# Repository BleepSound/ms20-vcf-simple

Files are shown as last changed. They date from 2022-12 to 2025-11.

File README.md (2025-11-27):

[][cc-by-sa]

# MS20 VCF

Latest documentation available at https://bleepsound.github.io/modules/

[][cc-by-sa]

[cc-by-sa]: http://creativecommons.org/licenses/by-sa/4.0/
[cc-by-sa-image]: https://licensebuttons.net/l/by-sa/4.0/88x31.png
[cc-by-sa-shield]: https://img.shields.io/badge/License-CC%20BY--SA%204.0-lightgrey.svg

[][cc-by-sa]

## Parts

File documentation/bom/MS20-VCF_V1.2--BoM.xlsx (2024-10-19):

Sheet: BoM
MS20-VCF_V1.2 Bill of Materials
Schematic: | MS20-VCF | Component Groups: | 22
Variant: | default | Component Count: | 55 (0 SMD/ 53 THT)
Revision: | 1.2 | Fitted Components: | 55 (0 SMD/ 53 THT)
Date: | 2024-10-19 | Number of PCBs: | 1
KiCad Version: | 8.0.6-8.0.6-0~ubuntu22.04.1 | Total Components: | 55
Row | Description | References | Value | Quantity Per PCB | Comments
1 |  | C1 C4 C5 | 1nF | 3
2 |  | C7 C8 C9 C10 | 100nF | 4
3 |  | C2 C3 C6 | 10uF | 3
4 |  | CUTCV1 CUTOFF1 Res1 | 100k | 3
5 |  | D2 D3 D4 D5 D6 D7 | 1N4148 | 6
6 |  | D1 | LED-12V | 1
7 |  | FB1 FB2 | 10R | 2
8 |  | J6 J7 J8 | FilterCV1 | 3
9 |  | J5 | Power Input | 1
10 |  | Q1 Q2 | BC559 (https://www.onsemi.com/pub/Collateral/BC556BTA-D.pdf) | 2
11 |  | R1 R3 R12 R13 | 470 | 4
12 |  | R8 R21 R22 | 1k | 3
13 |  | R10 R19 | 1.8k | 2
14 |  | R4 R5 R9 R20 | 2.2k | 4
15 |  | R17 | 33k | 1
16 |  | R18 | 56k | 1
17 |  | R14 | 82k | 1
18 |  | R2 R6 R7 R11 R15 R16 | 100k | 6
19 |  | ResLv1 ResVol1 | 10k | 2
20 |  | SW1 | Hpass/Lpass Switch | 1
21 |  | U1 | LM13700 (http://www.ti.com/lit/ds/symlink/lm13700.pdf) | 1
22 |  | U2 | TL072 (http://www.ti.com/lit/ds/symlink/tl071.pdf) | 1

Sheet: Colors
Columns colors
KiCad Fields (default)
Generated Fields
User Fields
Empty Fields

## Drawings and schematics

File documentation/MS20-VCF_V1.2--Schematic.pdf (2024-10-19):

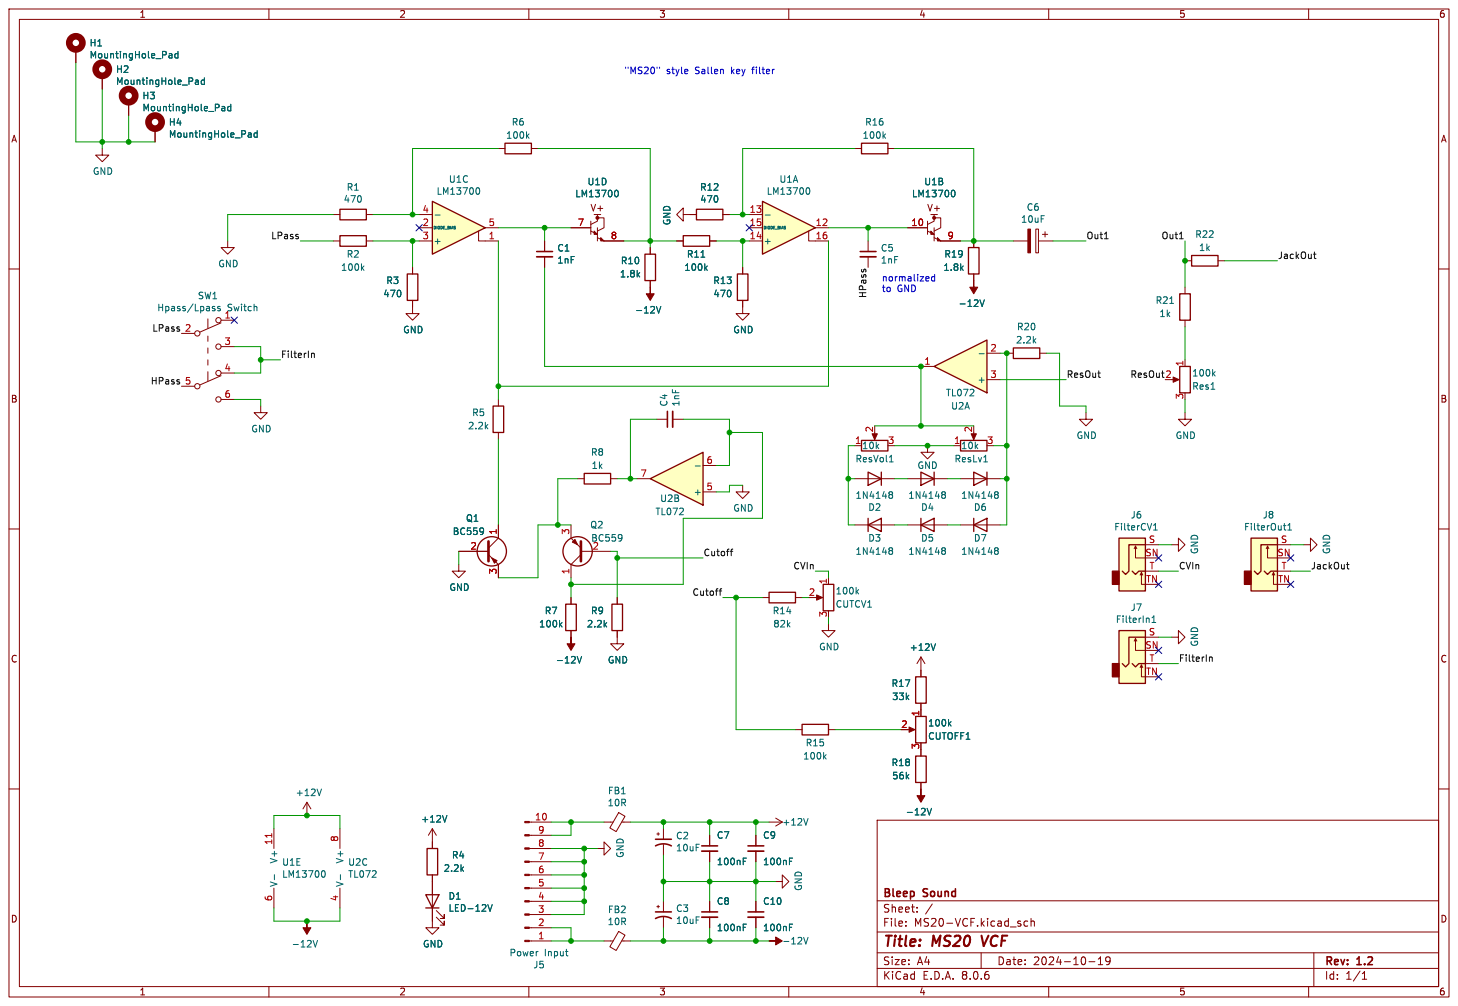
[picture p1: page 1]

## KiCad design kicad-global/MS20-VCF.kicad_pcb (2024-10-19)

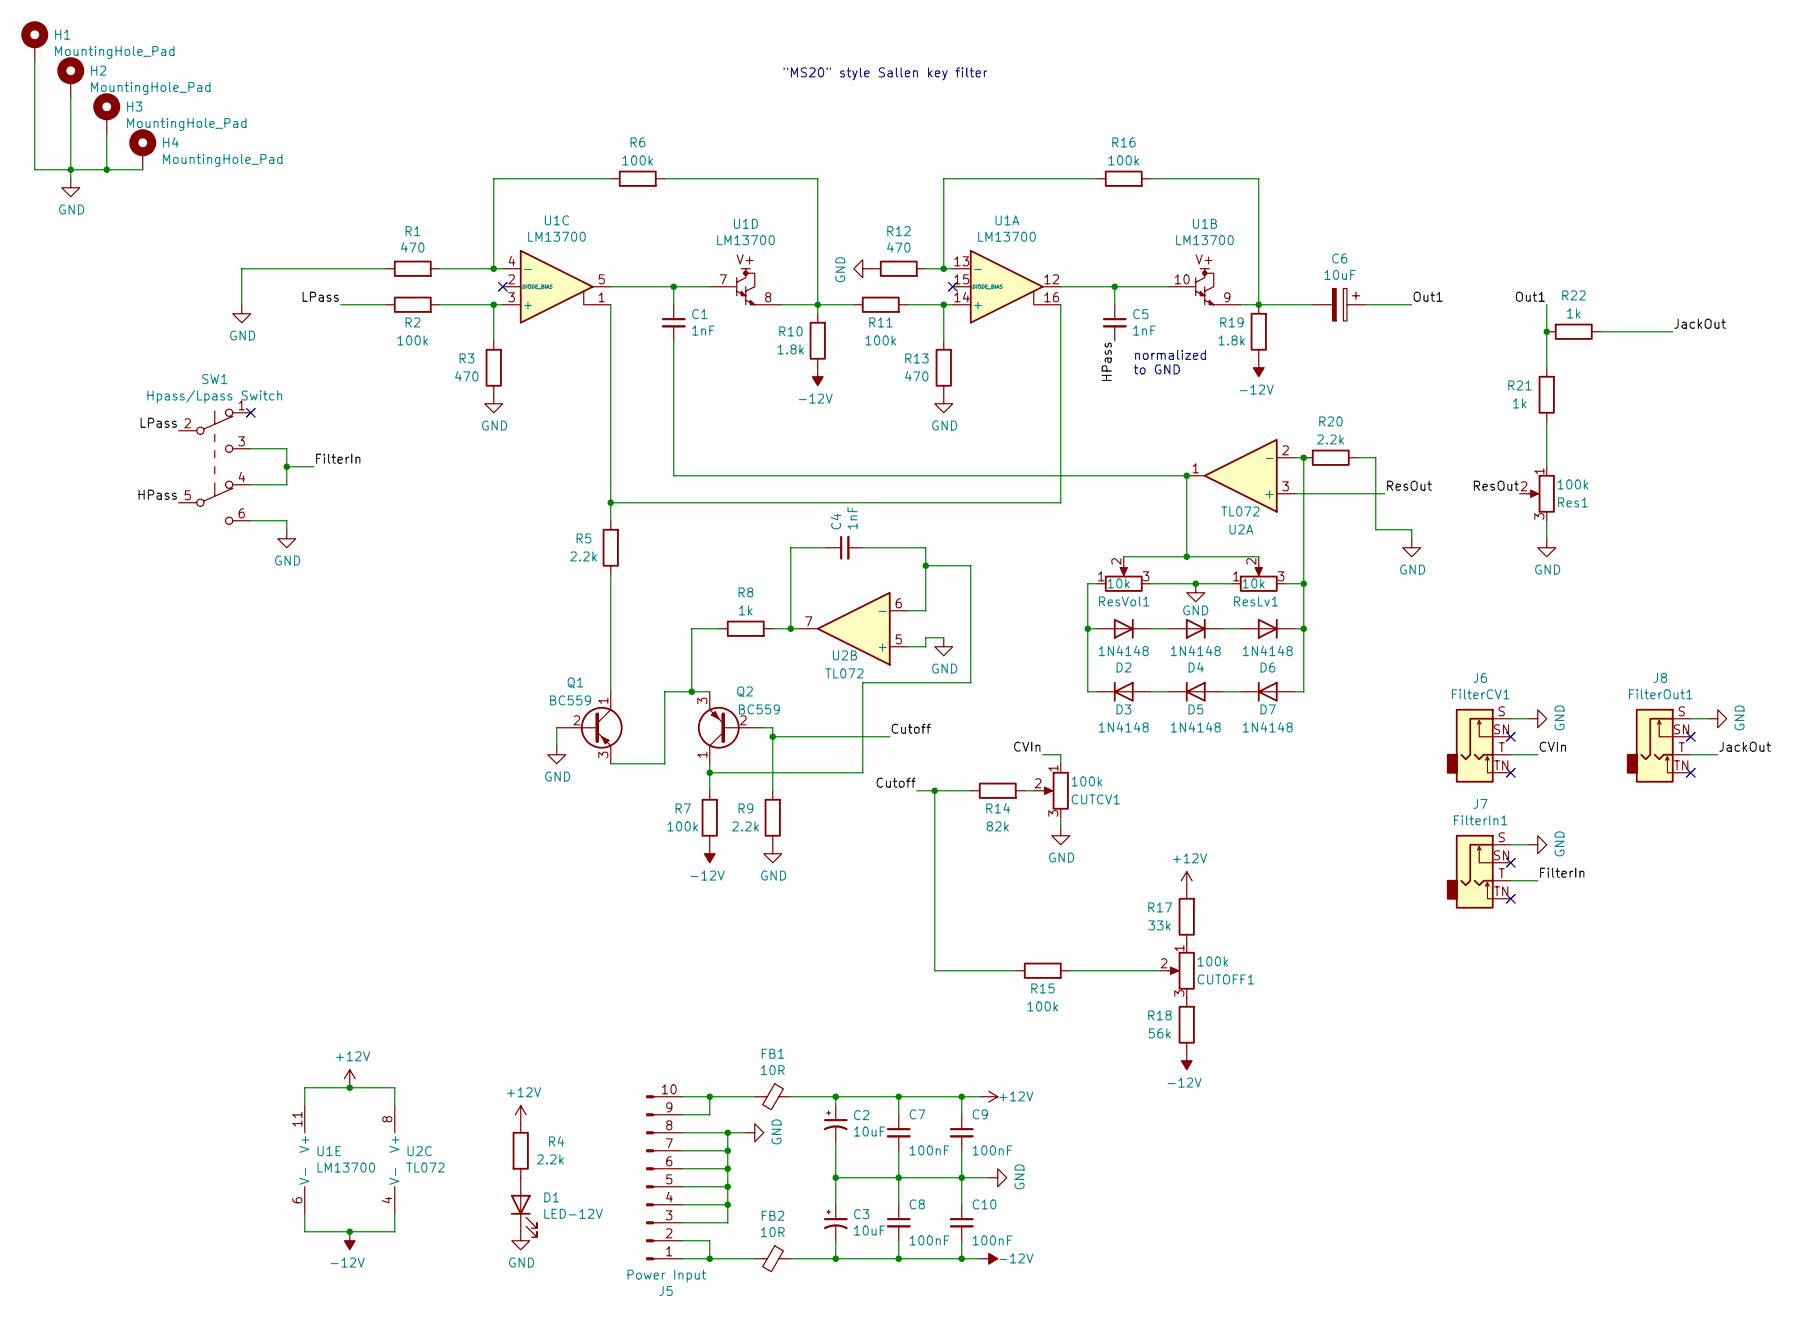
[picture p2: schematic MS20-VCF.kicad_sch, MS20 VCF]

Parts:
C1, C4, C5: 1nF; C_Disc_D7.0mm_W2.5mm_P5.00mm
C2, C3, C6: 10uF; CP_Radial_D5.0mm_P2.00mm
C7, C8, C9, C10: 100nF; C_Disc_D7.0mm_W2.5mm_P5.00mm
CUTCV1: 100k; Pot-bourns-alpha
CUTOFF1: 100k; Pot-bourns-alpha
D1: LED-12V; LED_D4.0mm
D2, D3, D4, D5, D6, D7: 1N4148; D_DO-35_SOD27_P7.62mm_Horizontal
FB1, FB2: 10R; L_Axial_L9.5mm_D4.0mm_P12.70mm_Horizontal_Fastron_SMCC
H1, H2, H3, H4: MountingHole_Pad; Doepfer Mounting hole
J5: Power Input; IDC-Header_2x05_P2.54mm_Vertical
J6: FilterCV1; Thonkiconn
J7: FilterIn1; Thonkiconn
J8: FilterOut1; Thonkiconn
Q1, Q2: BC559; TO-92_Inline_Wide
R1, R3, R12, R13: 470; R_Axial_DIN0207_L6.3mm_D2.5mm_P10.16mm_Horizontal
R2, R6, R7, R11, R15, R16: 100k; R_Axial_DIN0207_L6.3mm_D2.5mm_P10.16mm_Horizontal
R4, R5, R9, R20: 2.2k; R_Axial_DIN0207_L6.3mm_D2.5mm_P10.16mm_Horizontal
R8, R21, R22: 1k; R_Axial_DIN0207_L6.3mm_D2.5mm_P10.16mm_Horizontal
R10, R19: 1.8k; R_Axial_DIN0207_L6.3mm_D2.5mm_P10.16mm_Horizontal
R14: 82k; R_Axial_DIN0207_L6.3mm_D2.5mm_P10.16mm_Horizontal
R17: 33k; R_Axial_DIN0207_L6.3mm_D2.5mm_P10.16mm_Horizontal
R18: 56k; R_Axial_DIN0207_L6.3mm_D2.5mm_P10.16mm_Horizontal
Res1: 100k; Pot-bourns-alpha
ResLv1: 10k; Potentiometer_Bourns_3386C_Horizontal
ResVol1: 10k; Potentiometer_Bourns_3386C_Horizontal
SW1: Hpass/Lpass Switch; SW_DPDT_Toggle
U1: LM13700; SOIC-16_3.9x9.9mm_P1.27mm
U2: TL072; DIP-8_W7.62mm_Socket

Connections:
+12V: C2.1, C7.1, C9.1, FB1.1, R4.1, R17.2, U1.11 (V+), U2.8 (V+)
-12V: C3.2, C8.2, C10.2, FB2.1, R7.1, R10.1, R18.1, R19.1, U1.6 (V-), U2.4 (V-)
/CVIn: CUTCV1.1, J6.T
/Cutoff: Q2.2 (B), R9.2, R14.1, R15.1
/FilterIn: J7.T, SW1.3 (C), SW1.4 (A)
/HPass: C5.2, SW1.5 (B)
/JackOut: J8.T, R22.1
/LPass: R2.1, SW1.2 (B)
/Out1: C6.1, R21.2, R22.2
/ResOut: Res1.2, U2.3 (+)
GND: C2.2, C3.1, C7.2, C8.1, C9.2, C10.1, CUTCV1.3, D1.1 (K), H1.1, H2.1, H3.1, H4.1, J5.3, J5.4, J5.5, J5.6, J5.7, J5.8, J6.S, J7.S, J8.S, Q1.2 (B), R1.1, R3.1, R9.1, R12.1, R13.1, R20.1, Res1.3, ResLv1.1, ResVol1.3, SW1.6 (C), U2.5 (+)
unnamed: C1.1, U1.5, U1.7
unnamed: C1.2, ResLv1.2, ResVol1.2, U2.1
unnamed: C4.1, R8.2, U2.7
unnamed: C4.2, Q2.1 (C), R7.2, U2.6 (-)
unnamed: C5.1, U1.10, U1.12
unnamed: C6.2, R16.2, R19.2, U1.9
unnamed: CUTCV1.2, R14.2
unnamed: CUTOFF1.1, R17.1
unnamed: CUTOFF1.2, R15.2
unnamed: CUTOFF1.3, R18.2
unnamed: D1.2 (A), R4.2
unnamed: D2.1 (K), D4.2 (A)
unnamed: D2.2 (A), D3.1 (K), ResVol1.1
unnamed: D3.2 (A), D5.1 (K)
unnamed: D4.1 (K), D6.2 (A)
unnamed: D5.2 (A), D7.1 (K)
unnamed: D6.1 (K), D7.2 (A), R20.2, ResLv1.3, U2.2 (-)
unnamed: FB1.2, J5.9, J5.10
unnamed: FB2.2, J5.1, J5.2
unnamed: Q1.1 (C), R5.1
unnamed: Q1.3 (E), Q2.3 (E), R8.1
unnamed: R1.2, R6.1, U1.4 (-)
unnamed: R2.2, R3.2, U1.3 (+)
unnamed: R5.2, U1.1, U1.16
unnamed: R6.2, R10.2, R11.1, U1.8
unnamed: R11.2, R13.2, U1.14 (+)
unnamed: R12.2, R16.1, U1.13 (-)
unnamed: R21.1, Res1.1

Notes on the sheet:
normalized to GND
"MS20" style Sallen key filter

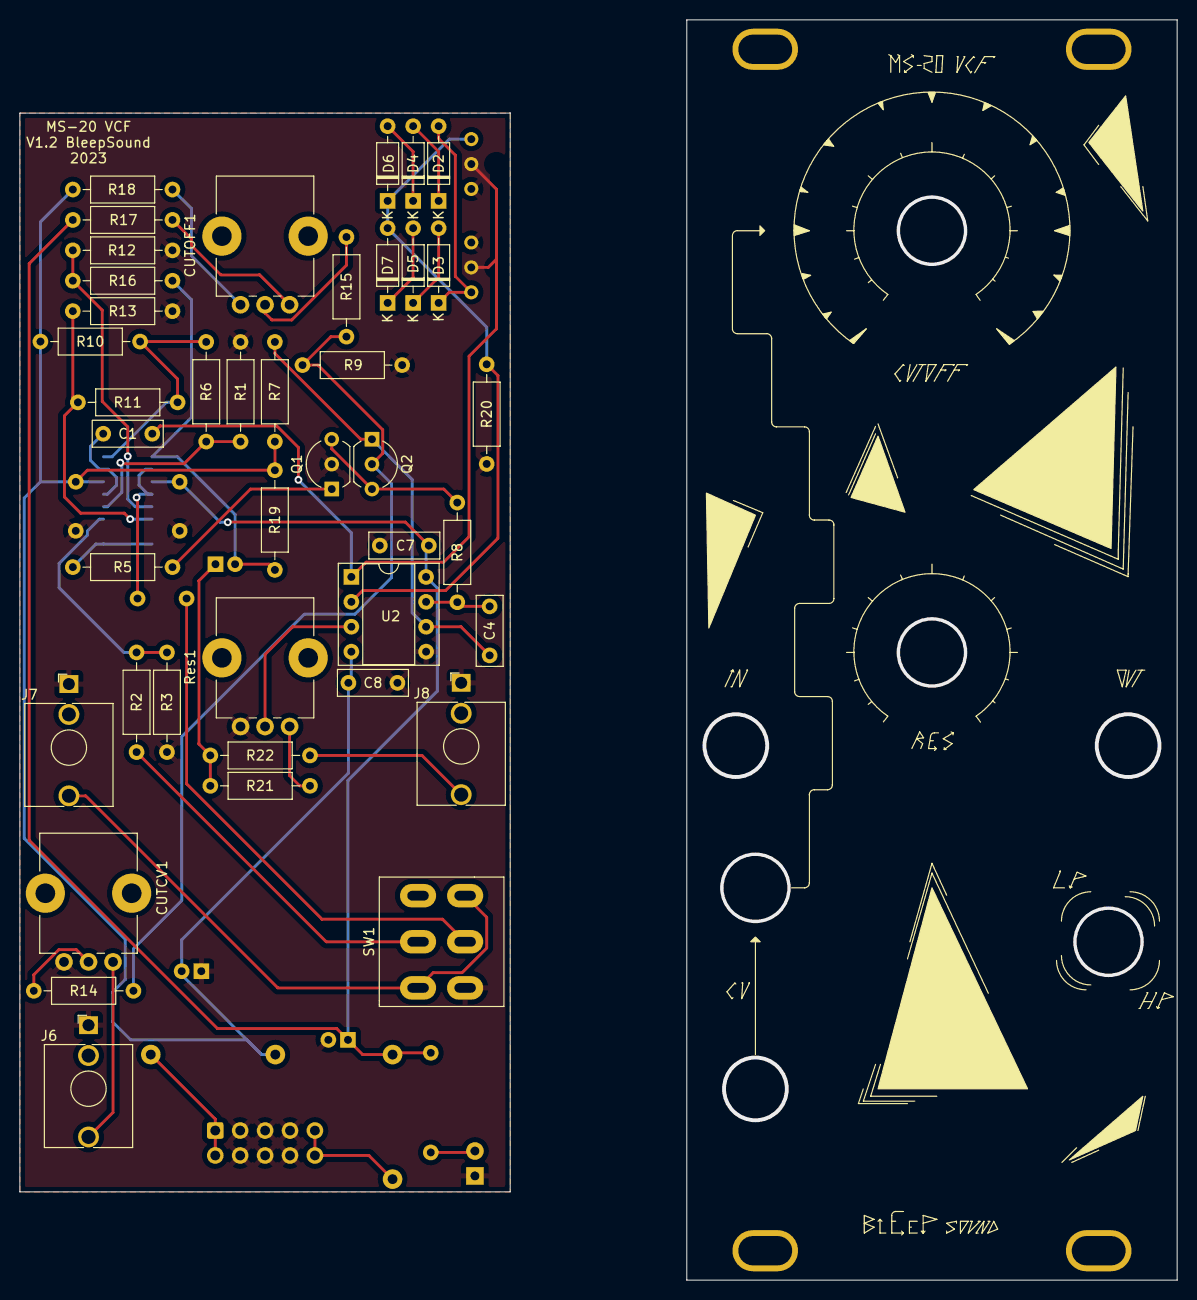
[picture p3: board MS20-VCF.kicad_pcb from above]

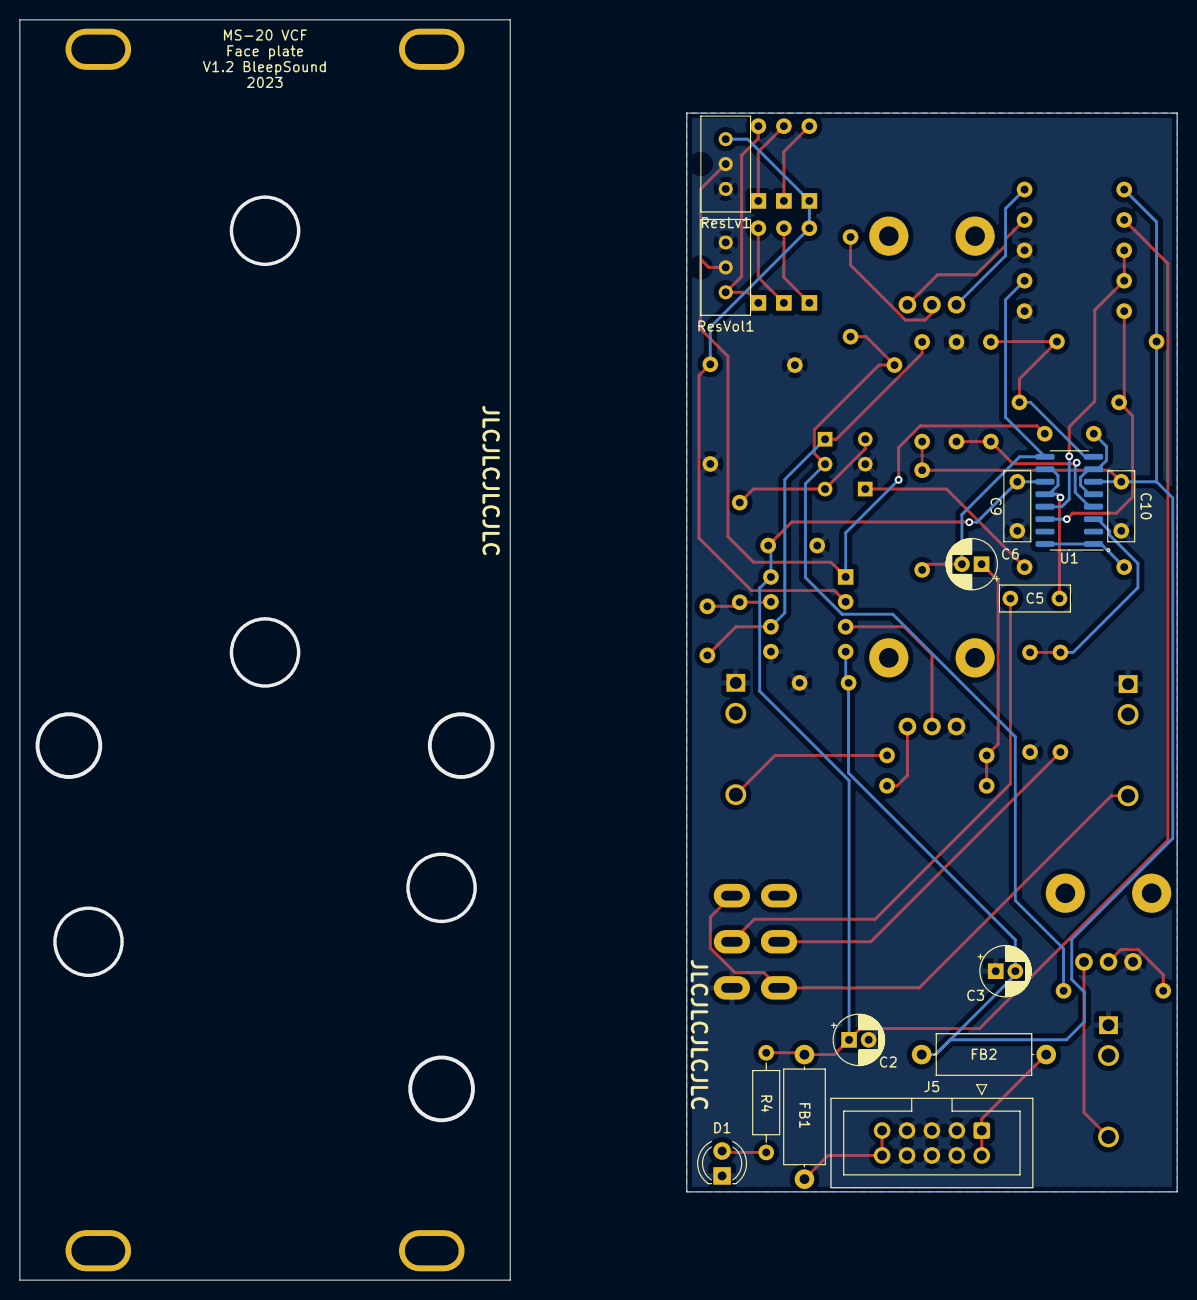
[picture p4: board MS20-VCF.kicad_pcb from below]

Board: 2 copper layers, 50.0 x 110.0 mm, 59 parts (14 on the bottom side), 39 nets.

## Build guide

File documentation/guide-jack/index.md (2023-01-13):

---
## layout: single

# Populate Manual for MS20-VCF

Follow this manual to populate the PCB:

The basic rule is, always go from the smallest to the highest component on the board !

####  This is the front side of the board we are populating

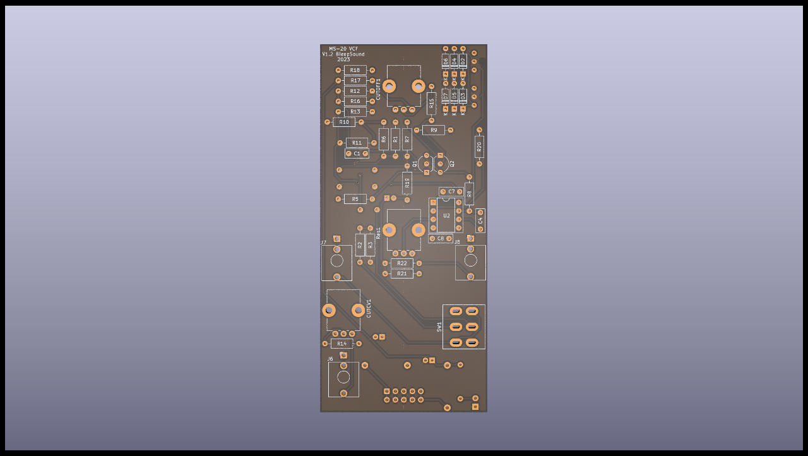
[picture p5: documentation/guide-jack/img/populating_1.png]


####  This is the back side of the board we are populating, and we are gonna start by this side.

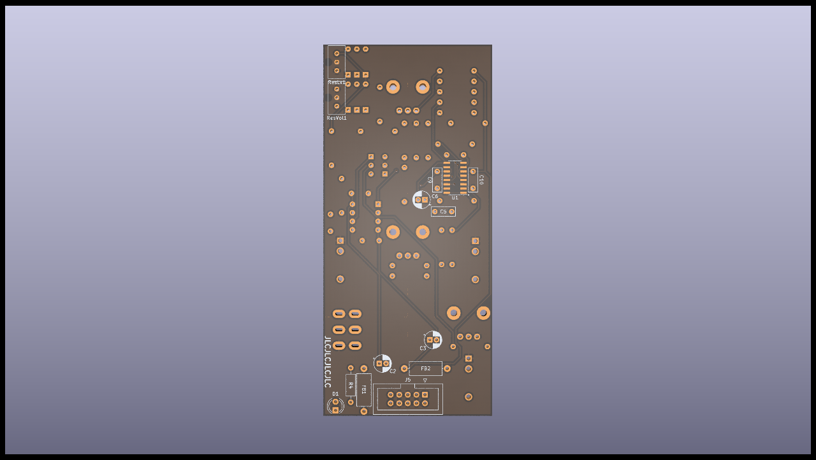
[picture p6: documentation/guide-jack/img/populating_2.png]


####  Start by the SMD components, here U1.

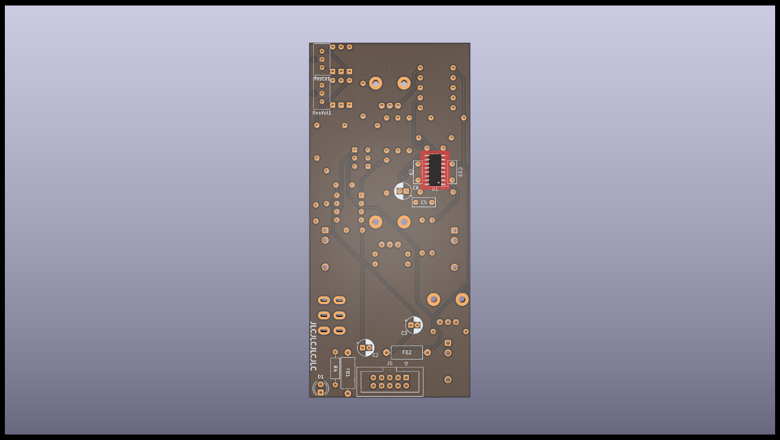
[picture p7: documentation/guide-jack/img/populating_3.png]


####  After U1, do the beads and the resistor

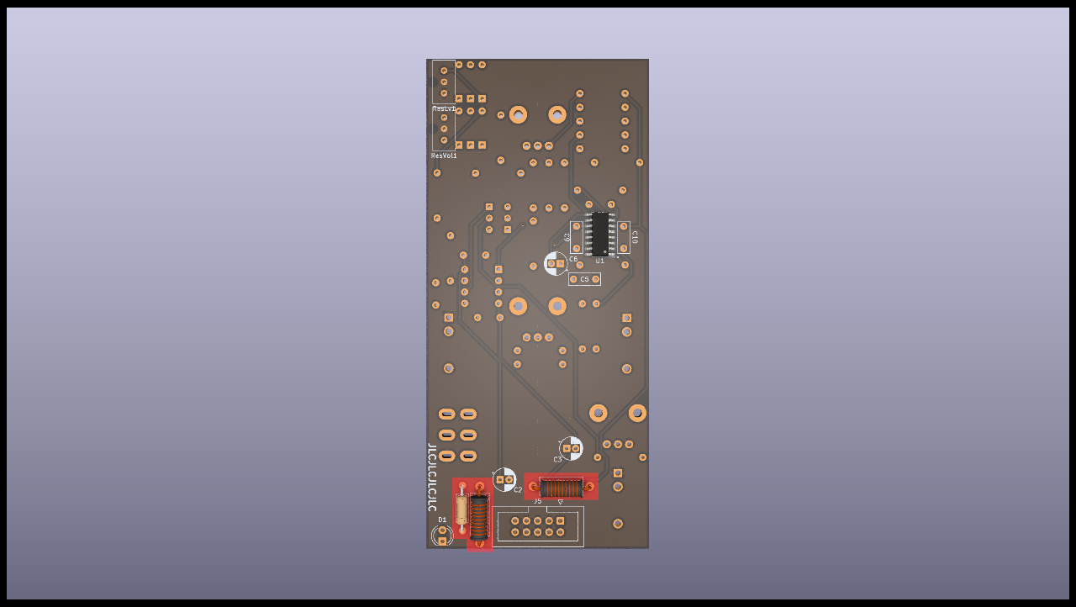
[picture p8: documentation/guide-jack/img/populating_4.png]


####  Do all the ceramic capacitors

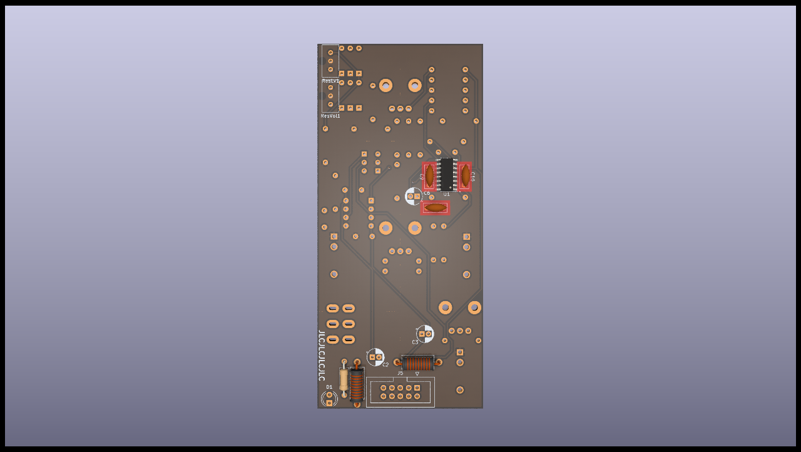
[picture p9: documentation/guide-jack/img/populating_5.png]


####  Finish the capacitors with the electrolytic ones, watch out for their orientation, they are polarized.

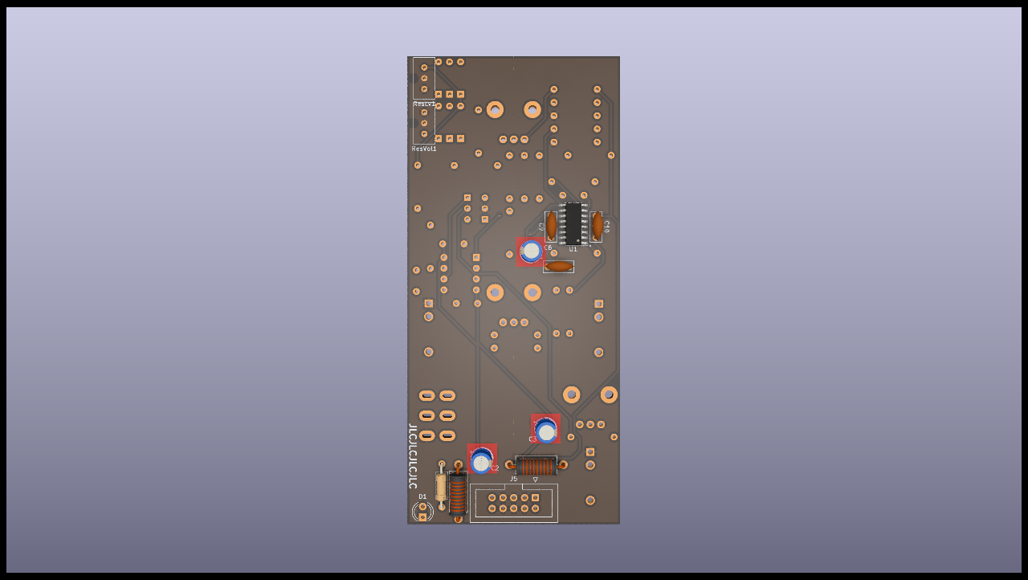
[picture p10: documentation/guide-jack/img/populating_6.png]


####  Finish the back by putting the trimmers, the power LED and the power connector. The LED shouldn't touch the backside of the PCB.

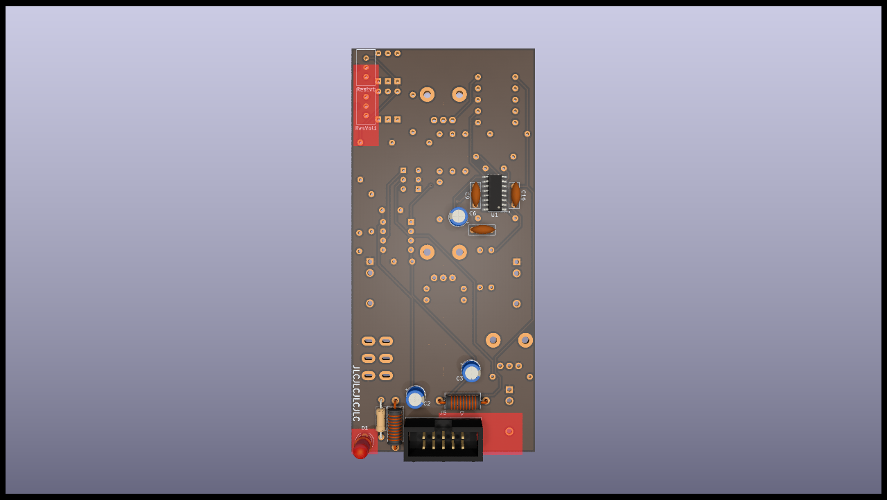
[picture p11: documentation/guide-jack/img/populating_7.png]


The back is done, we can flip the PCB and start the front !

#### 

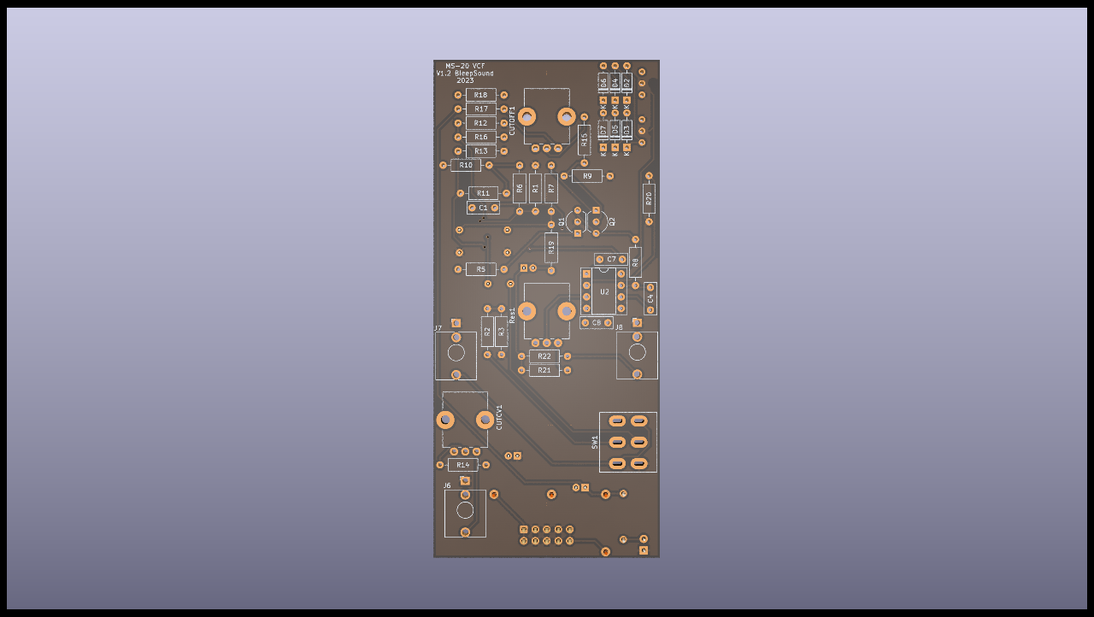
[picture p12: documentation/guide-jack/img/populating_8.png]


####  First, populate all the diodes.

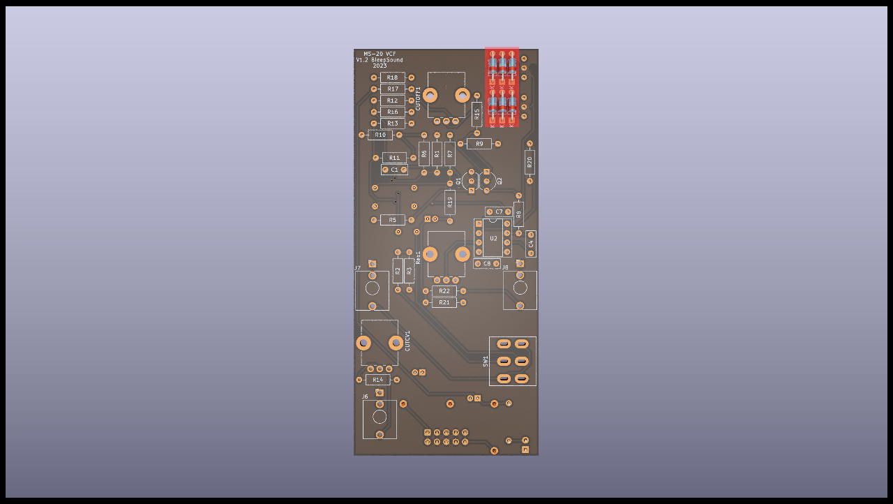
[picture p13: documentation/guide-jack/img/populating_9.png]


####  You then can do all the resistors (by value so you don't make mistakes)

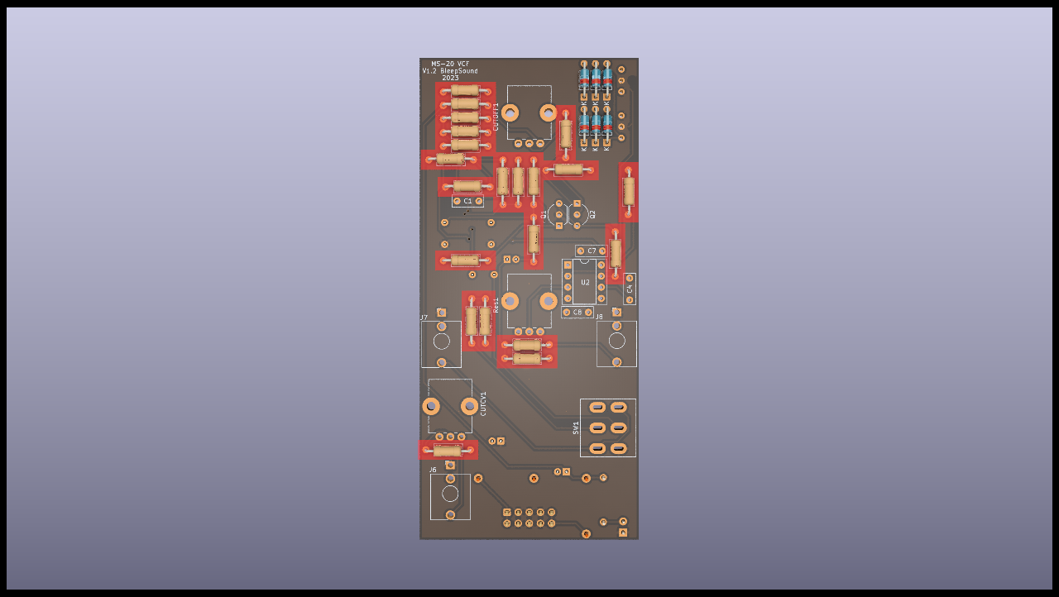
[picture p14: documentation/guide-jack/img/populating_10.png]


####  You then can add the transitors, watch out for their orientation.

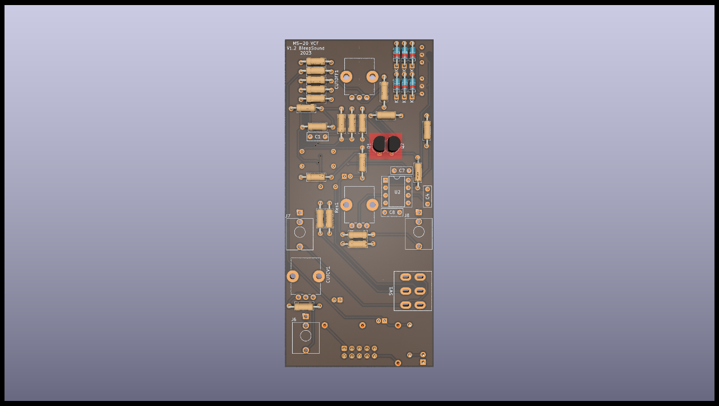
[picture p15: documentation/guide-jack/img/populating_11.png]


####  Add the socket for the TL072, making sure you get the orientation right. Don't add the Tl072 yet, you'll add it at the end.

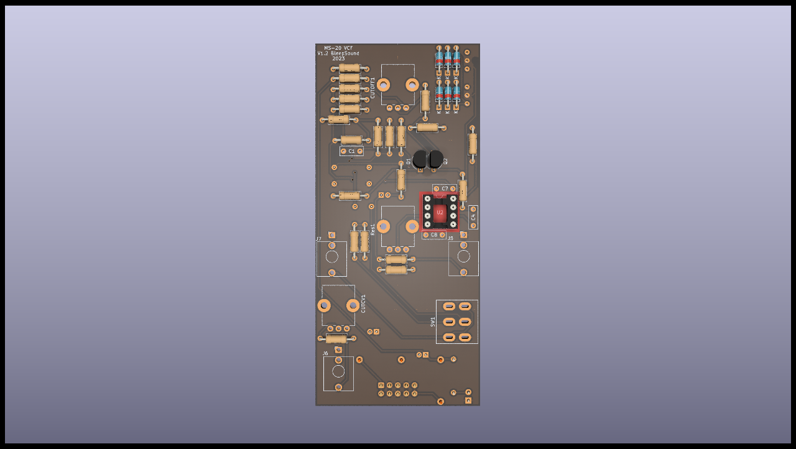
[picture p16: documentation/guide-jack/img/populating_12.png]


####  Add the capacitors

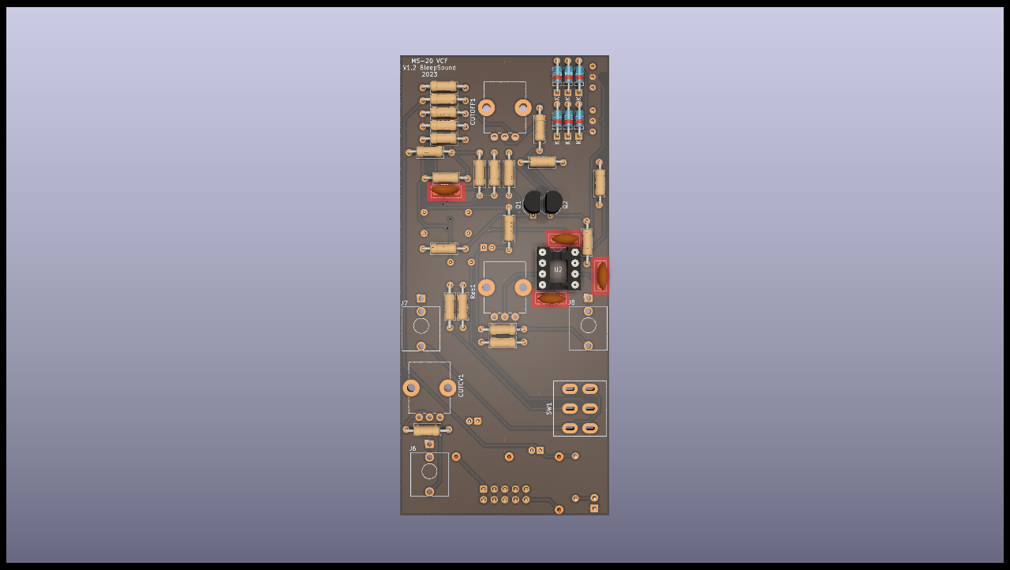
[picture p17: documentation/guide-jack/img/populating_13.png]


The last step concern the jacks, potentiometers and switches. Basically, anything that is accessible throught the front panel. You first place them.

:warning: DO NOT SOLDER THEM YET :warning:

(this is really important !!)

####  Do Not Solder Them! place them first and put the front panel in place. _For the pot __CUTCV1__ , use the small 100k pot (not D shaped)_  The other pots are for CUTOFF1 and Res1. You'll be able to put the" knobs of your choice on those.

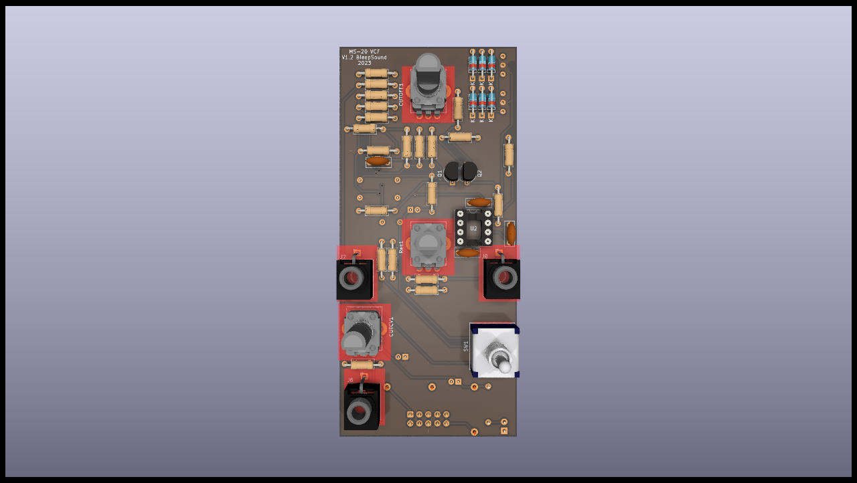
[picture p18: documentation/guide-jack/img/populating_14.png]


You then put in place the front panel, making sure everything fits. Once all the jack sockets and switches are fastenned to the front panel, you can solder them, and only then !!!

## Conclusion

This is the end of the build, if yoy have any questions, don't hesitate !

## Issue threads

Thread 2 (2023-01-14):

Problème constaté lors de l'atelier du 14 janvier

MartinDelille, 2023-01-14:
- [x] Manque un détrompeur sur le CMS

arthursaunier, 2023-01-15:
Alors en fait il y en a un. Sur la serigraphie, tu as un cote avec une barre longue qui specifie la pin 1. Mais je peux ajouter un truc en plus pour que ce soit plus visible.

arthursaunier, 2023-01-15:
J'ai rajoute une marque suplementaire du coup.

Closed 2023-01-15.

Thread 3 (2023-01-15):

Création du module sur modulargrid

MartinDelille, 2023-01-15:
Je voulais créer le module sur https://www.modulargrid.net/ et j'ai besoin de ces infos:

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

arthursaunier, 2023-01-15:
Jamais fait de mesure, il faudrait que je fasse ca.

arthursaunier, 2023-02-18:
Module créé
https://www.modulargrid.net/e/other-unknown-bleepsound-ms20-vcf

MartinDelille, 2023-02-20:
Il faudrait le rajouter au readme à l'occase.

Closed 2023-02-18.

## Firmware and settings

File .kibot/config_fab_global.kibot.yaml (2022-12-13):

# This is a working example.
# For a more complete reference use `--example`
kibot:
  version: 1

global:
  filters:
  - number: 1007
  - number: 1015
  - number: 58

filters:
- name: only_jlc_parts
  comment: Only parts with JLC (LCSC) code
  type: generic
  include_only:
  - column: LCSC#
    regex: ^C\d+

variants:
- name: place_holder
  comment: Just a place holder for pre_transform filters
  type: kicost
  pre_transform:
  - _kicost_rename
  - _rot_footprint

outputs:
- name: basic_boardview
  comment: Board View export
  type: boardview
  dir: Assembly

- name: generic_bom_xlsx
  comment: Generic Bill of Materials in XLSX format
  type: bom
  dir: BoM/Generic
  options:
    format: XLSX
    count_smd_tht: true

- name: gerber_modern
  comment: Gerbers in modern format, recommended by the standard
  type: gerber
  dir: Gerbers_and_Drill
  layers:
  - layer: F.Cu
    suffix: F_Cu
    description: Front copper
  - layer: B.Cu
    suffix: B_Cu
    description: Bottom copper
  - layer: B.Paste
    suffix: B_Paste
    description: Bottom solder paste
  - layer: B.Silkscreen
    suffix: B_Silkscreen
    description: Bottom silkscreen (artwork)
  - layer: F.Silkscreen
    suffix: F_Silkscreen
    description: Front silkscreen (artwork)
  - layer: B.Mask
    suffix: B_Mask
    description: Bottom soldermask (negative)
  - layer: F.Mask
    suffix: F_Mask
    description: Front soldermask (negative)
  - layer: User.Drawings
    suffix: User_Drawings
    description: User drawings
  - layer: User.Comments
    suffix: User_Comments
    description: User comments
  - layer: Edge.Cuts
    suffix: Edge_Cuts
    description: Board shape
  - layer: B.Courtyard
    suffix: B_Courtyard
    description: Bottom courtyard area
  - layer: F.Courtyard
    suffix: F_Courtyard
    description: Front courtyard area
  - layer: B.Fab
    suffix: B_Fab
    description: Bottom documentation
  - layer: F.Fab
    suffix: F_Fab
    description: Front documentation

- name: JLCPCB_gerbers
  comment: Gerbers compatible with JLCPCB
  type: gerber
  dir: Manufacturers/JLCPCB
  options:
    exclude_edge_layer: true
    exclude_pads_from_silkscreen: true
    plot_sheet_reference: false
    plot_footprint_refs: true
    plot_footprint_values: false
    force_plot_invisible_refs_vals: false
    tent_vias: true
    use_protel_extensions: true
    create_gerber_job_file: false
    disable_aperture_macros: true
    gerber_precision: 4.6
    use_gerber_x2_attributes: false
    use_gerber_net_attributes: false
    line_width: 0.1
    subtract_mask_from_silk: true
    inner_extension_pattern: .gp%n
  layers: &id002
  - layer: F.Cu
    suffix: F_Cu
    description: Front copper
  - layer: B.Cu
    suffix: B_Cu
    description: Bottom copper
  - layer: B.Paste
    suffix: B_Paste
    description: Bottom solder paste
  - layer: B.Silkscreen
    suffix: B_Silkscreen
    description: Bottom silkscreen (artwork)
  - layer: F.Silkscreen
    suffix: F_Silkscreen
    description: Front silkscreen (artwork)
  - layer: B.Mask
    suffix: B_Mask
    description: Bottom soldermask (negative)
  - layer: F.Mask
    suffix: F_Mask
    description: Front soldermask (negative)
  - layer: Edge.Cuts
    suffix: Edge_Cuts
    description: Board shape
- name: JLCPCB_drill
  comment: Drill files compatible with JLCPCB
  type: excellon
  dir: Manufacturers/JLCPCB
  options:
    pth_and_npth_single_file: false
    pth_id: -PTH
    npth_id: -NPTH
    metric_units: true
    map: gerber
    route_mode_for_oval_holes: false
    output: '%f%i.%x'
- name: JLCPCB_position
  comment: Pick and place file, JLCPCB style
  type: position
  dir: Manufacturers/JLCPCB
  options:
    variant: place_holder
    output: '%f_cpl_jlc.%x'
    format: CSV
    units: millimeters
    separate_files_for_front_and_back: false
    only_smd: true
    columns:
    - id: Ref
      name: Designator
    - Val
    - Package
    - id: PosX
      name: Mid X
    - id: PosY
      name: Mid Y
    - id: Rot
      name: Rotation
    - id: Side
      name: Layer
- name: JLCPCB_bom
  comment: BoM for JLCPCB
  type: bom
  dir: Manufacturers/JLCPCB
  options:
    output: '%f_%i_jlc.%x'
    exclude_filter: only_jlc_parts
    ref_separator: ','
    columns:
    - field: Value
      name: Comment
    - field: References
      name: Designator
    - Footprint
    - field: LCSC#
      name: 'LCSC Part #'
    csv:
      hide_pcb_info: true
      hide_stats_info: true
      quote_all: true
- name: JLCPCB
  comment: ZIP file for JLCPCB
  type: compress
  dir: Manufacturers
  options:
    files:
    - from_output: JLCPCB_gerbers
      dest: /
    - from_output: JLCPCB_drill
      dest: /
    - from_output: JLCPCB_position
      dest: /
    - from_output: JLCPCB_bom
      dest: /

- name: basic_ibom
  comment: Interactive HTML BoM
  type: ibom
  dir: Assembly
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

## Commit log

2022-12-13 init commit with base files (kibot files empty)
    [MS20-VCF-front.kicad_pcb, MS20-VCF-jackboard.kicad_pcb, MS20-VCF.kicad_pcb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]
2022-12-19 update workflow
    [MS20-VCF.kicad_pcb]
2022-12-21 add gerber workflow
2022-12-21 add main BoM and images
    [MS20-VCF-bom.xlsx]
2022-12-21 add comit for jack bom
2022-12-21 add jack BoM
2022-12-28 Add custom 3d models
    [MS20-VCF.kicad_pcb, PJ301M-12 Thonkiconn v0.2.stp, RK09K1130AH1.STEP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]
2022-12-28 comment useless gerber gen
2022-12-28 add commit to gerber + comment useless tag
2022-12-28 add front gerber
    [MS20-VCF--NPTH_map.gbr, MS20-VCF--PTH_map.gbr, MS20-VCF-B_Cu.gbl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]
2022-12-28 fix gerber gen files
2022-12-28 add jack gerber
    [MS20-VCF--NPTH_map.gbr, MS20-VCF--PTH_map.gbr, MS20-VCF-B_Cu.gbl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]
2022-12-28 fix issue of folder creqtions
    [MS20-VCF--NPTH_map.gbr, MS20-VCF--PTH_map.gbr, MS20-VCF-B_Cu.gbl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]
2023-01-10 change output to pcbdraw
2023-01-11 move populate to have only concerned board
2023-01-11 trying to fix issue with populate comd
    [MS20-VCF.kicad_sch]
2023-01-11 update readme and kicab pcb for jackboard (fix 3d parts issue)
    [MS20-VCF.kicad_pcb]
2023-01-11 update excel bom conf
2023-01-12 add details and fix issues
    [MS20-VCF.kicad_sch]
2023-01-12 lowercase dir
    [MS20-VCF--NPTH_map.gbr, MS20-VCF--PTH_map.gbr, MS20-VCF-B_Cu.gbl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]
2023-01-13 update bom gen
2023-01-15 update footprint trimmer
    [MS20-VCF-bom.xlsx, MS20-VCF.kicad_pcb, MS20-VCF.kicad_sch]
2023-01-15 add extra silkscreen info for smd components
    [MS20-VCF.kicad_pcb]
2023-01-15 update to v1.2 on silkscreen
    [MS20-VCF.kicad_pcb]
2023-02-18 update footprint for trimmer
    [MS20-VCF.kicad_pcb, MS20-VCF.kicad_sch]
2024-10-19 update repo organization
    [MS20-VCF--NPTH_map.gbr, MS20-VCF--PTH_map.gbr, MS20-VCF-B_Cu.gbl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]

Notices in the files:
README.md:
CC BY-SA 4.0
